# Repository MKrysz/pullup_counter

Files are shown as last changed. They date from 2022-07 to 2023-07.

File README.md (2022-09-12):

# Pullup Counter

## About

The main purpose of the project was to automatically count and save the amount of pullups I do to evaluate them later using python script. For this purpose I developed a small device mounted onto the bar. Other features include display for showing how many pullups were already done that day and USB serial port for easy to use interface with the device.

## Hardware

### PCB

Schematic

Schematic and PCB was made in KiCad.

For the power supply I decided that 2 AAA batteries would be the best choice, as they're easily available and have good volumetric energy density. Embedding the Li-Po battery was out of the table, because the project is stationary and charging wouldn't be possible.

As the brain of the device I went with STM32L0 series microcontroller because of following reasons:

- low power consumption and low operating voltage, which is mandatory in battery operated systems like this
- my familiarity with developing both harware and software development with this series
- affordable price.

I chose a STM32L051C8 as I had few of them lying around.

The MCU has a backup battery used for maintaining operation of RTC clock while main batteries are discharged or being replaced. The amount of pullups are displayed on 7 segment display as it's cheap, small and easy to drive. It's also perfect for displaying numbers which is all It's used here for. For a memory in which I would store my database i used a 512kB SPI Flash - P25Q40H. Communication with the device is done with USB serial port, so I included an USB port and USB-UART converter. I also included a capacitive touch pad and little sensor IC as a way to wake the device up. For detecting pullups I used proximity sesor consisting of IR Led diode and photodiode.

PCBs were manufactured by JLCPCB, and are shown below:
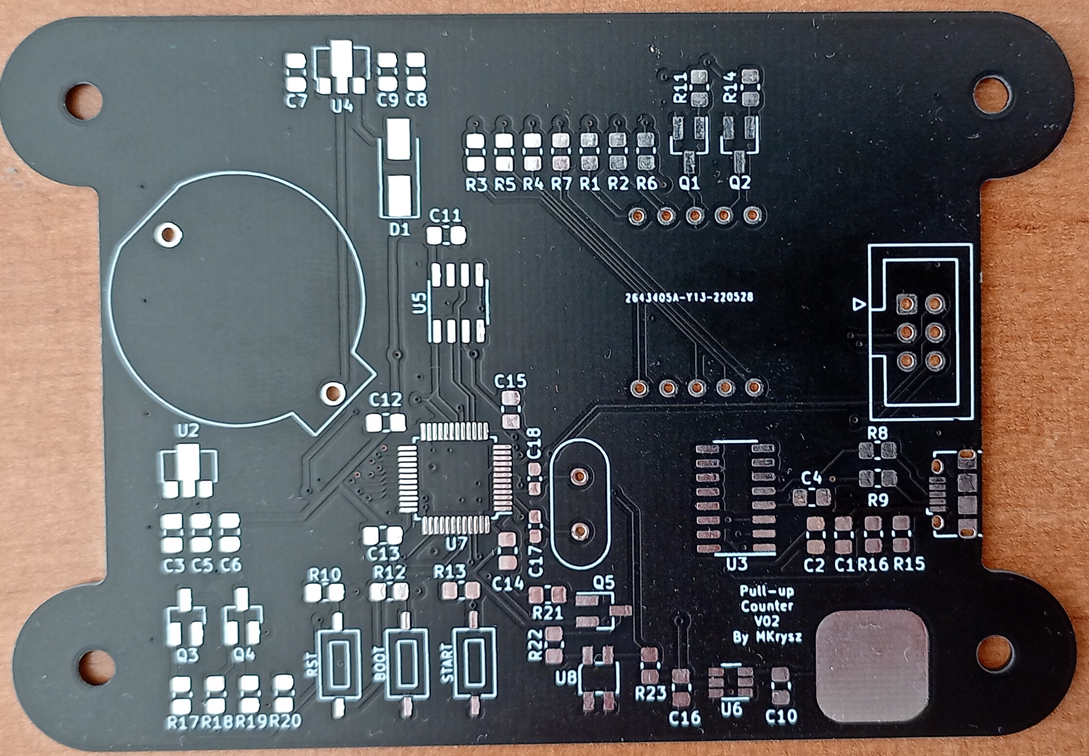
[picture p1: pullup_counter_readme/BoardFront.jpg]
Front

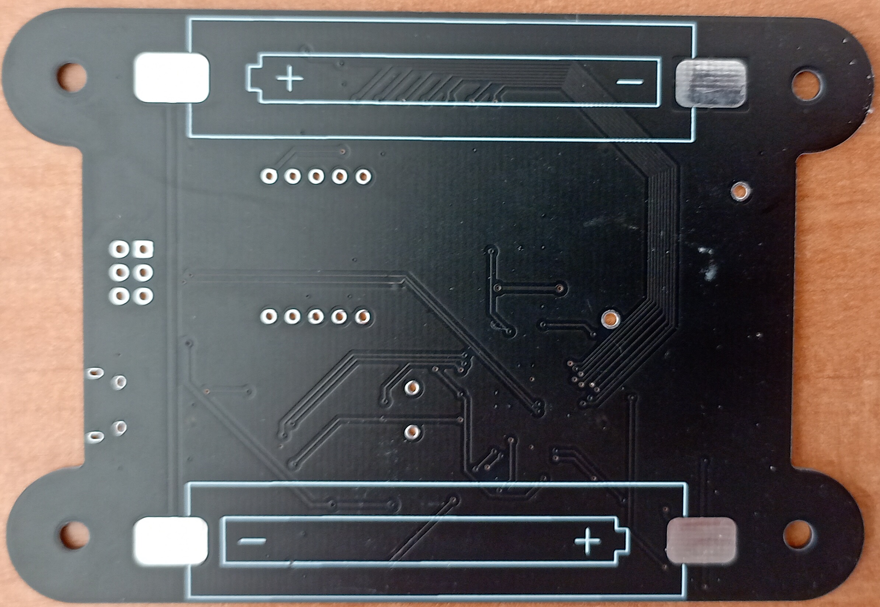
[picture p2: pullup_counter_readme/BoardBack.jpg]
Back


During soldering I found out that I'm out of SMD proximity sensors so I glued a THT one instead. Also, by accident, I soldered PNP transistors instead of NPN. After replacing the transistors I had to connect them to different pins of the MCU as the original ones were blown up.

After assembling and mounting it on the pullup bar:

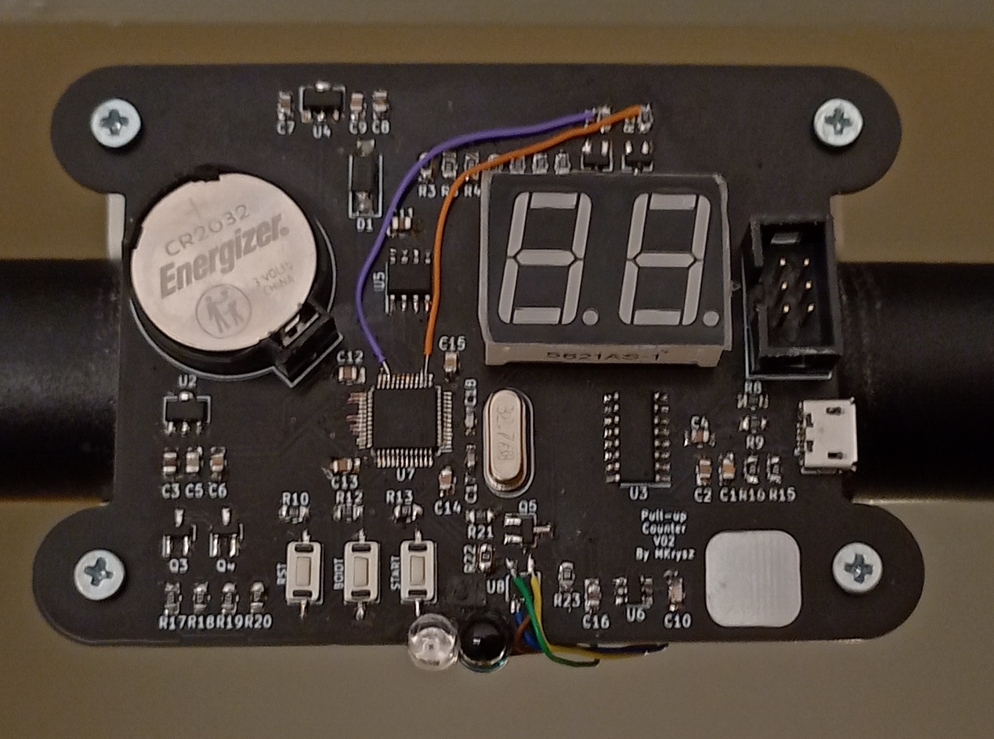
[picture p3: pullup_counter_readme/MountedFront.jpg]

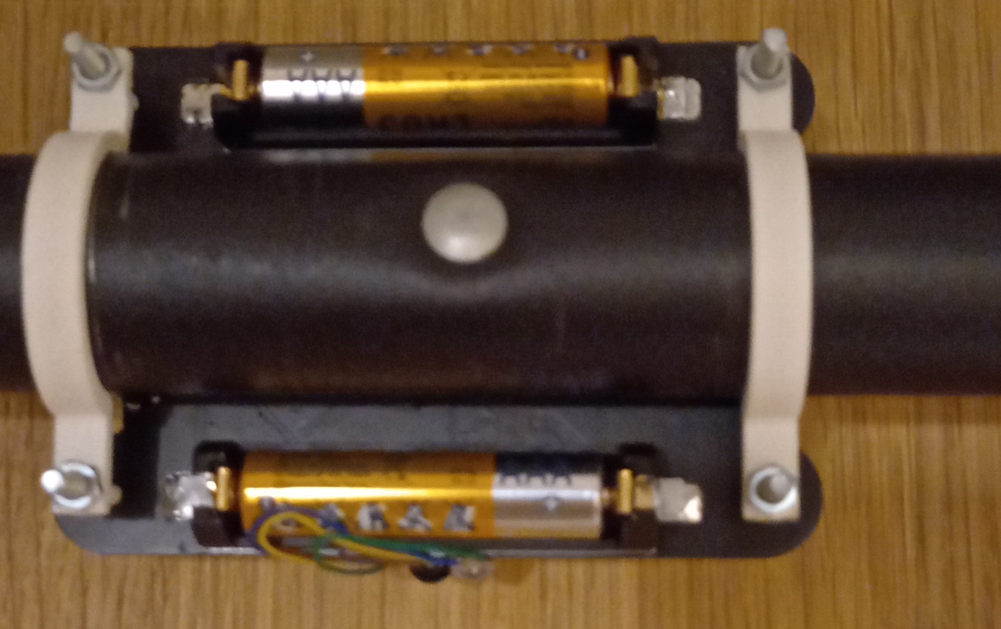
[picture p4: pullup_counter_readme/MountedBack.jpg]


### Mounting

Mounting is done using 3D-printed mounting system and four pairs of M3 bolts and nuts.

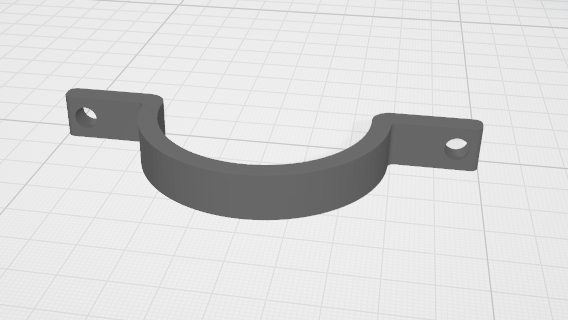
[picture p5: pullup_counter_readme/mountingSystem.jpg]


## Software

### Embedded

Project was made in VSCode using [stm32-for-vscode](https://github.com/bmd-studio/stm32-for-vscode) extension. For this project I used [stm32CubeMX](https://www.st.com/en/development-tools/stm32cubemx.html) for generating initialization code. I've also used nimaltd's [drivers for SPI flash memory](https://github.com/nimaltd/w25qxx).

The device must be woken up before every training session, which can be done either by physical button or capacitive touch pad. After that if device haven't detected a pullup within specified time, it goes back to sleep to prolong battery life.

Every pullup series is represented with following struct

```C

typedef struct _entry_struct
{
    uint32_t id; // unique id
    unsigned int count:6; // amount of pullups done in the series

    // timestamp
    unsigned int minute:6;
    unsigned int hour:5;
    unsigned int day:5;
    unsigned int month:4;
    unsigned int year:6;
}entry_t;

```

Because each entry's size is 8 bytes and my flash memory is 512kB the maximum amount of pullups that can be saved within the device is over 65 thousand

### USB User Interface

User interface allows the user for easy change of important parameters, debugging and downloading and  clearing data from device's flash memory. To put device in interface mode, plug it in your computer and restart it. The welcome message should appear. After that you can type 'help' for a list of available commands with short description.

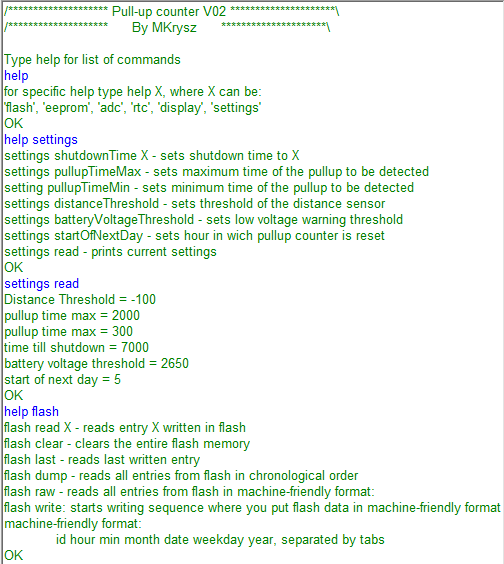
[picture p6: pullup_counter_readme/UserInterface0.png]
User Interface


### Data analysis

Python script that reads and interprets data acquired from the device.

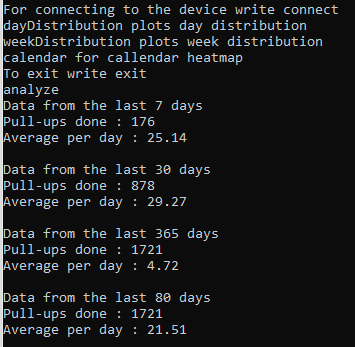
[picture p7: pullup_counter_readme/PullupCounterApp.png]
PullupCounterApp


Below are shown examples of generated plots:
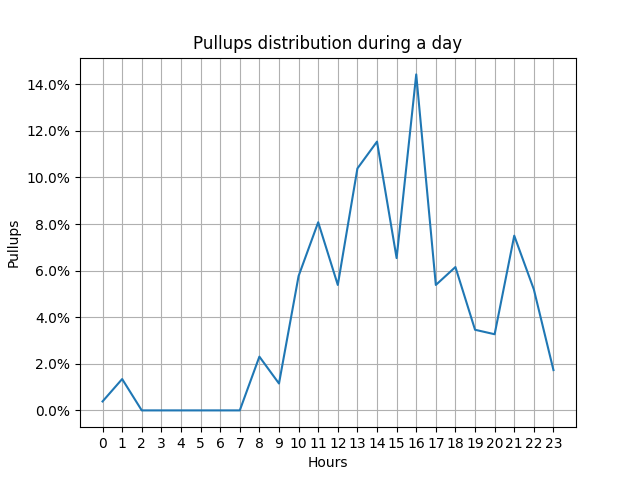
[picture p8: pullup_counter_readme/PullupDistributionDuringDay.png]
DayPlot

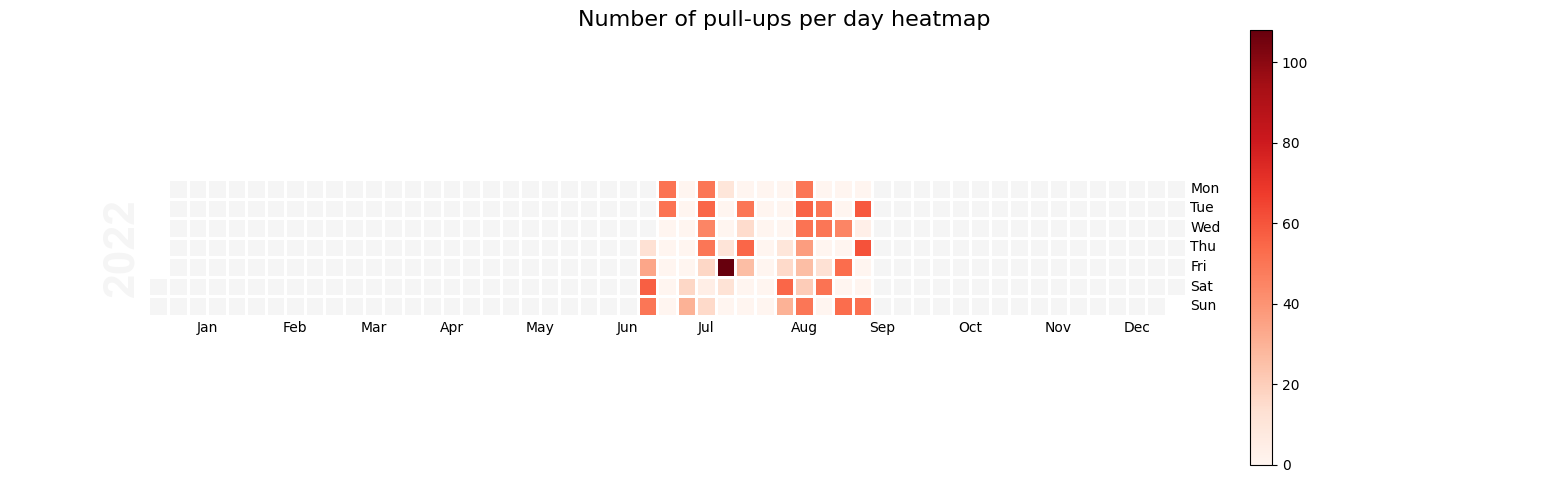
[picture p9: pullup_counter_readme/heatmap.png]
Heatmap


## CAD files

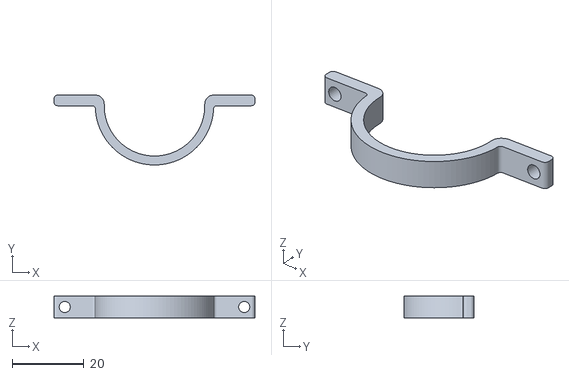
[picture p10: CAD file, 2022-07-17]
pullup_counter_models/mountingSystem.stl
56.0 x 19.5 x 6.00

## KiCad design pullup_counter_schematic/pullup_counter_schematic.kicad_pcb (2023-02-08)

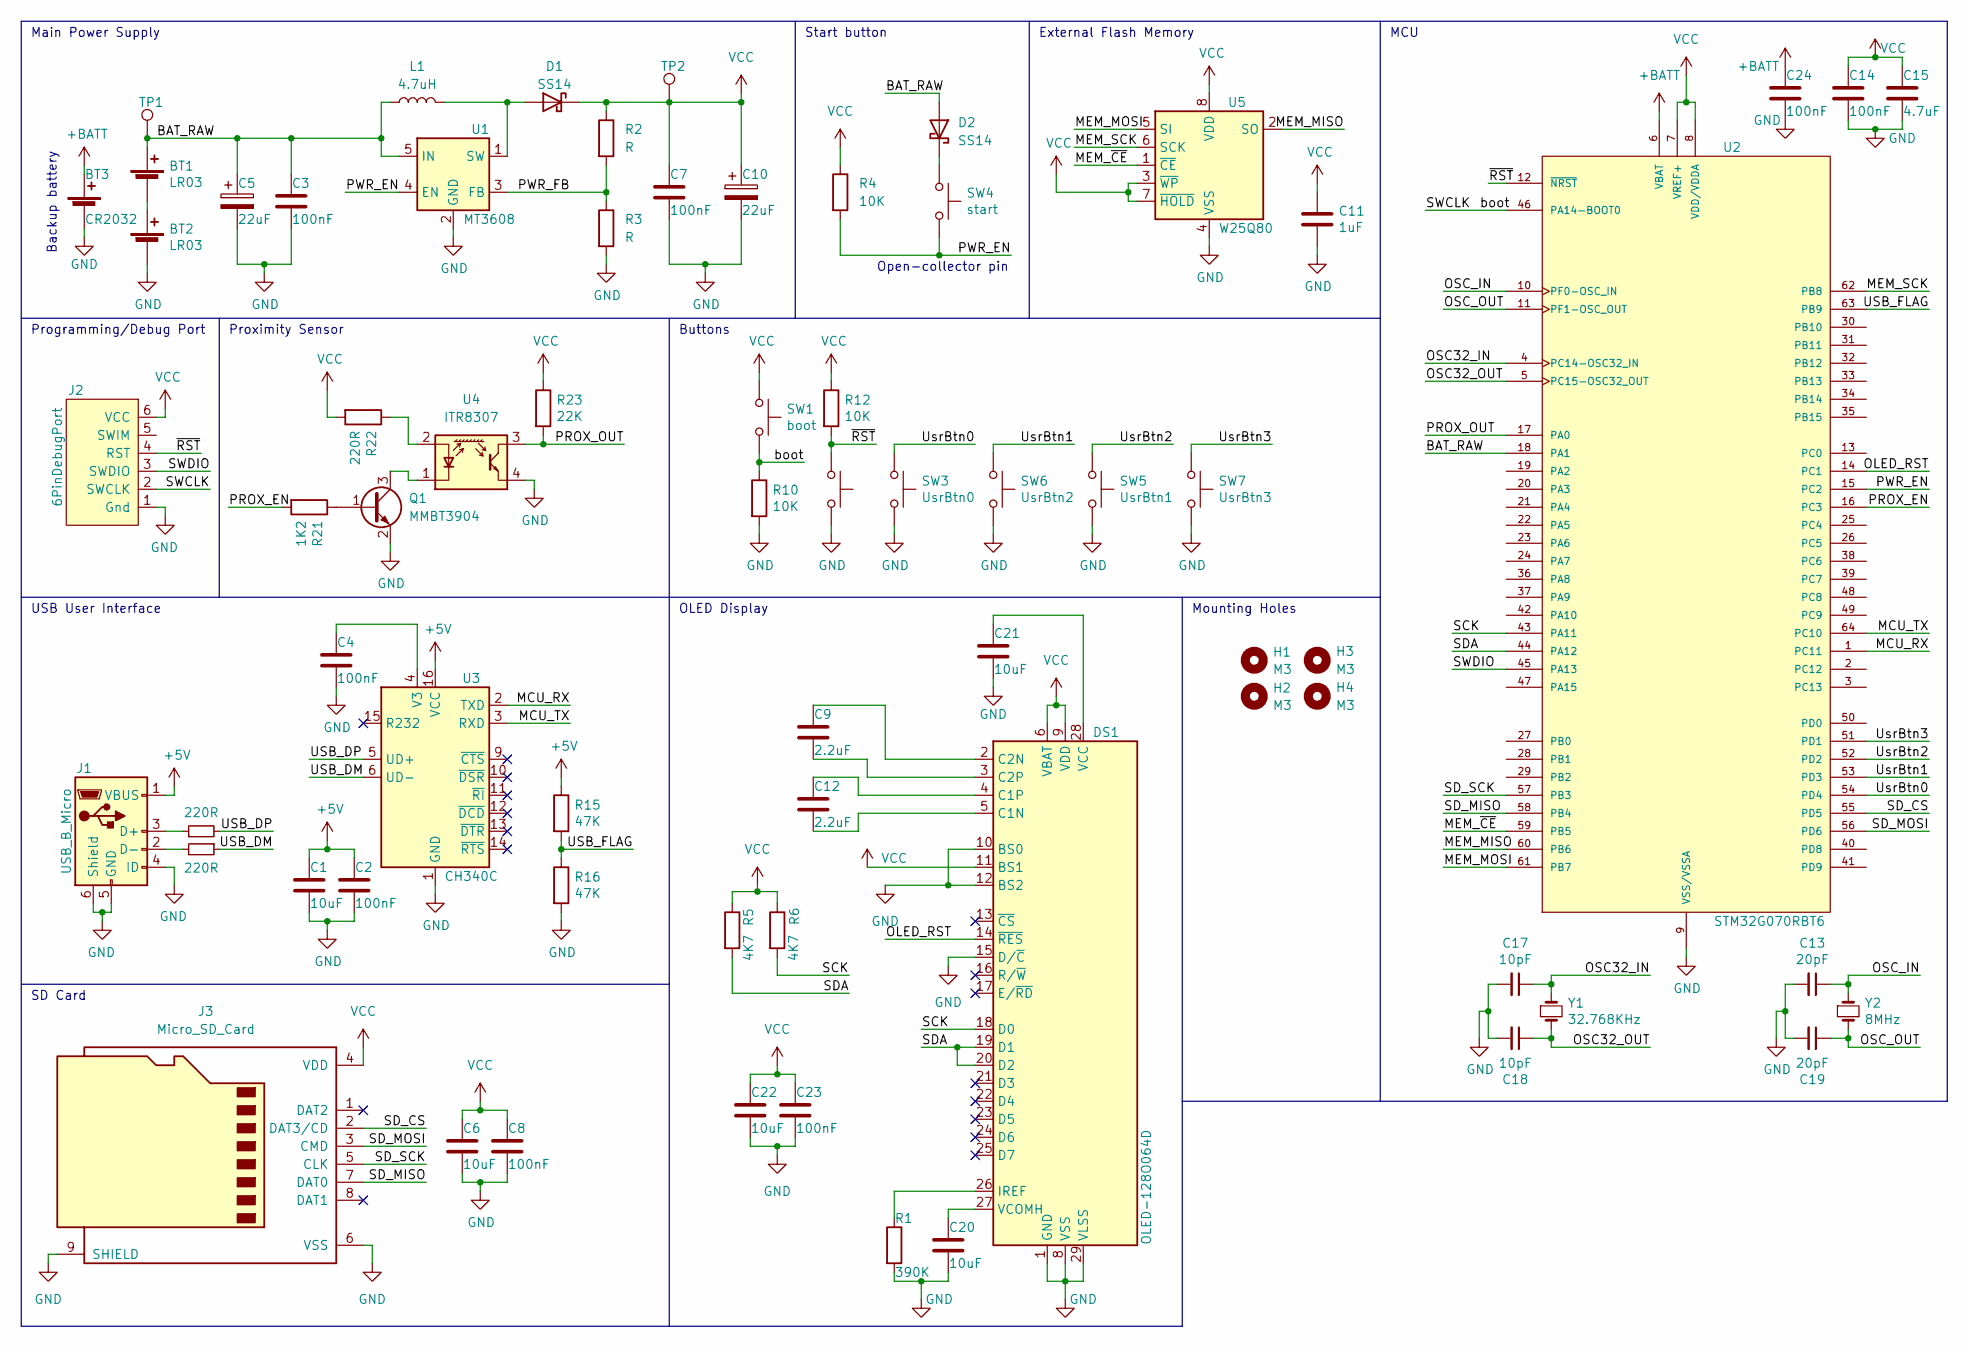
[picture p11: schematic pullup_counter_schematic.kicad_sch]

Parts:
BT1, BT2: LR03; SMD_SMT_AAA_LR03
BT3: CR2032; CR2032_CR2025_Battery_Holder
C1, C6, C20, C21, C22: 10uF; C_0805_2012Metric_Pad1.18x1.45mm_HandSolder
C2, C3, C4, C7, C8, C14, C23, C24: 100nF; C_0805_2012Metric_Pad1.18x1.45mm_HandSolder
C5, C10: 22uF; CP_Elec_5x4.5
C9, C12: 2.2uF; C_0805_2012Metric_Pad1.18x1.45mm_HandSolder
C11: 1uF; C_0805_2012Metric_Pad1.18x1.45mm_HandSolder
C13, C19: 20pF; C_0603_1608Metric_Pad1.08x0.95mm_HandSolder
C15: 4.7uF; C_0805_2012Metric_Pad1.18x1.45mm_HandSolder
C17, C18: 10pF; C_0603_1608Metric_Pad1.08x0.95mm_HandSolder
D1, D2: SS14; D_SMA
DS1: OLED-128O064D
H1, H2, H3, H4: M3; MountingHole_3.2mm_M3
J1: USB_B_Micro; USB_Micro-B_Amphenol_10118194_Horizontal
J2: 6PinDebugPort; IDC-Header_2x03_P2.54mm_Vertical
J3: Micro_SD_Card; uSD_socket
L1: 4.7uH; L_Ferrocore_DLG-0403
Q1: MMBT3904; SOT-23
R1: 390K; R_0805_2012Metric_Pad1.20x1.40mm_HandSolder
R2, R3: R; R_0805_2012Metric_Pad1.20x1.40mm_HandSolder
R4, R10, R12: 10K; R_0805_2012Metric_Pad1.20x1.40mm_HandSolder
R5, R6: 4K7; R_0805_2012Metric_Pad1.20x1.40mm_HandSolder
R8, R9, R22: 220R; R_0805_2012Metric_Pad1.20x1.40mm_HandSolder
R15, R16: 47K; R_0805_2012Metric_Pad1.20x1.40mm_HandSolder
R21: 1K2; R_0805_2012Metric_Pad1.20x1.40mm_HandSolder
R23: 22K; R_0805_2012Metric_Pad1.20x1.40mm_HandSolder
SW1: boot; TSB008
SW2: rst; TSB008
SW3: UsrBtn0; TSB008
SW4: start; sw_push_12_x_12_mm
SW5: UsrBtn1; TSB008
SW6: UsrBtn2; TSB008
SW7: UsrBtn3; TSB008
TP1, TP2: PinSocket_1x01_P2.54mm_Vertical
U1: MT3608; SOT-23-6
U2: STM32G070RBT6; LQFP-64_10x10mm_P0.5mm; PARTREV 1
U3: CH340C; SOIC-16_3.9x9.9mm_P1.27mm
U4: ITR8307; Everlight_ITR8307
U5: W25Q80; SOIC-8_5.275x5.275mm_P1.27mm
Y1: 32.768KHz; Crystal_HC49-4H_Vertical
Y2: 8MHz; Crystal_HC49-4H_Vertical

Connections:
+5V: C1.1, C2.1, J1.1 (VBUS), R15.1, U3.16 (VCC)
+BATT: BT3.1 (+), C24.1, U2.6 (VBAT)
/BAT_RAW: BT1.1 (+), C3.1, C5.1, D2.2 (A), L1.1, TP1.1, U1.5 (IN), U2.18 (PA1)
/MCU_RX: U2.1 (PC11), U3.2 (TXD)
/MCU_TX: U2.64 (PC10), U3.3 (RXD)
/MEM_MISO: U2.60 (PB6), U5.2 (SO)
/MEM_MOSI: U2.61 (PB7), U5.5 (SI)
/MEM_SCK: U2.62 (PB8), U5.6 (SCK)
/MEM_~CE: U2.59 (PB5), U5.1 (~CE)
/OLED_RST: DS1.14 (~RES), U2.14 (PC1)
/OSC32_IN: C17.1, U2.4 (PC14-OSC32_IN), Y1.1
/OSC32_OUT: C18.1, U2.5 (PC15-OSC32_OUT), Y1.2
/OSC_IN: C13.1, U2.10 (PF0-OSC_IN), Y2.1
/OSC_OUT: C19.1, U2.11 (PF1-OSC_OUT), Y2.2
/PROX_EN: R21.2, U2.16 (PC3)
/PROX_OUT: R23.2, U2.17 (PA0), U4.3 (C)
/PWR_EN: R4.2, SW4.2, U1.4 (EN), U2.15 (PC2)
/PWR_FB: R2.2, R3.1, U1.3 (FB)
/SCK: DS1.18 (D0), R6.2, U2.43 (PA11)
/SDA: DS1.19 (D1), DS1.20 (D2), R5.2, U2.44 (PA12)
/SD_CS: J3.2 (DAT3/CD), U2.55 (PD5)
/SD_MISO: J3.7 (DAT0), U2.58 (PB4)
/SD_MOSI: J3.3 (CMD), U2.56 (PD6)
/SD_SCK: J3.5 (CLK), U2.57 (PB3)
/SWCLK: J2.2 (SWCLK), R10.1, SW1.2, U2.46 (PA14-BOOT0)
/SWDIO: J2.3 (SWDIO), U2.45 (PA13)
/USB_DM: R9.1, U3.6 (UD-)
/USB_DP: R8.2, U3.5 (UD+)
/USB_FLAG: R15.2, R16.1, U2.63 (PB9)
/UsrBtn0: SW3.1, U2.54 (PD4)
/UsrBtn1: SW6.1, U2.53 (PD3)
/UsrBtn2: SW5.1, U2.52 (PD2)
/UsrBtn3: SW7.1, U2.51 (PD1)
/~RST: J2.4 (RST), R12.2, SW2.1, U2.12 (~NRST)
GND: BT2.2 (-), BT3.2 (-), C1.2, C2.2, C3.2, C4.2, C5.2, C6.2, C7.2, C8.2, C10.2, C11.2, C13.2, C14.2, C15.2, C17.2, C18.2, C19.2, C20.2, C21.2, C22.2, C23.2, C24.2, DS1.1 (GND), DS1.8 (VSS), DS1.10 (BS0), DS1.12 (BS2), DS1.15 (D/~C), DS1.29 (VLSS), DS1.30 (GND), J1.4 (ID), J1.5 (GND), J1.6 (Shield), J2.1 (Gnd), J3.6 (VSS), J3.9 (SHIELD), Q1.2 (E), R1.2, R3.2, R10.2, R16.2, SW2.2, SW3.2, SW5.2, SW6.2, SW7.2, U1.2 (GND), U2.9 (VSS/VSSA), U3.1 (GND), U4.4 (E), U5.4 (VSS)
unnamed: BT1.2 (-), BT2.1 (+)
unnamed: C4.1, U3.4 (V3)
unnamed: C9.1, DS1.2 (C2N)
unnamed: C9.2, DS1.3 (C2P)
unnamed: C12.1, DS1.4 (C1P)
unnamed: C12.2, DS1.5 (C1N)
unnamed: C20.1, DS1.27 (VCOMH)
unnamed: D1.2 (A), L1.2, U1.1 (SW)
unnamed: D2.1 (K), SW4.1
unnamed: DS1.26 (IREF), R1.1
unnamed: C21.1, DS1.28 (VCC)
unnamed: J1.2 (D-), R9.2
unnamed: J1.3 (D+), R8.1
unnamed: Q1.1 (B), R21.1
unnamed: Q1.3 (C), U4.1 (K)
unnamed: R22.1, U4.2 (A)
VCC: C6.1, C7.1, C8.1, C10.1, C11.1, C14.1, C15.1, C22.1, C23.1, D1.1 (K), DS1.6 (VBAT), DS1.9 (VDD), DS1.11 (BS1), J2.6 (VCC), J3.4 (VDD), R2.1, R4.1, R5.1, R6.1, R12.1, R22.2, R23.1, SW1.1, TP2.1, U2.7 (VREF+), U2.8 (VDD/VDDA), U5.3 (~WP), U5.7 (~HOLD), U5.8 (VDD)

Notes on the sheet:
OLED Display
USB User Interface
Main Power Supply
Programming/Debug Port
Open-collector pin
Backup battery
External Flash Memory
MCU
Start button
Proximity Sensor
Mounting Holes
SD Card
Buttons

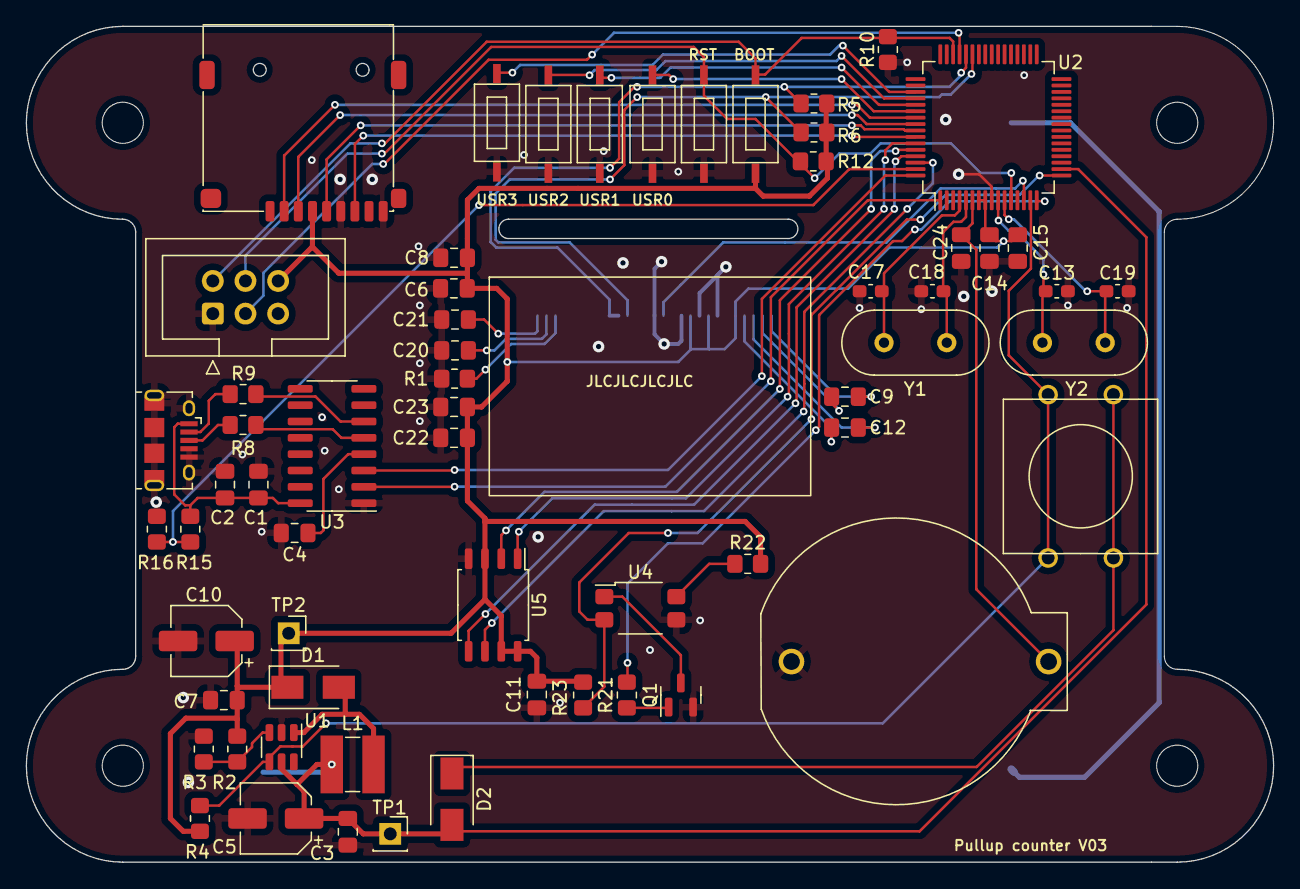
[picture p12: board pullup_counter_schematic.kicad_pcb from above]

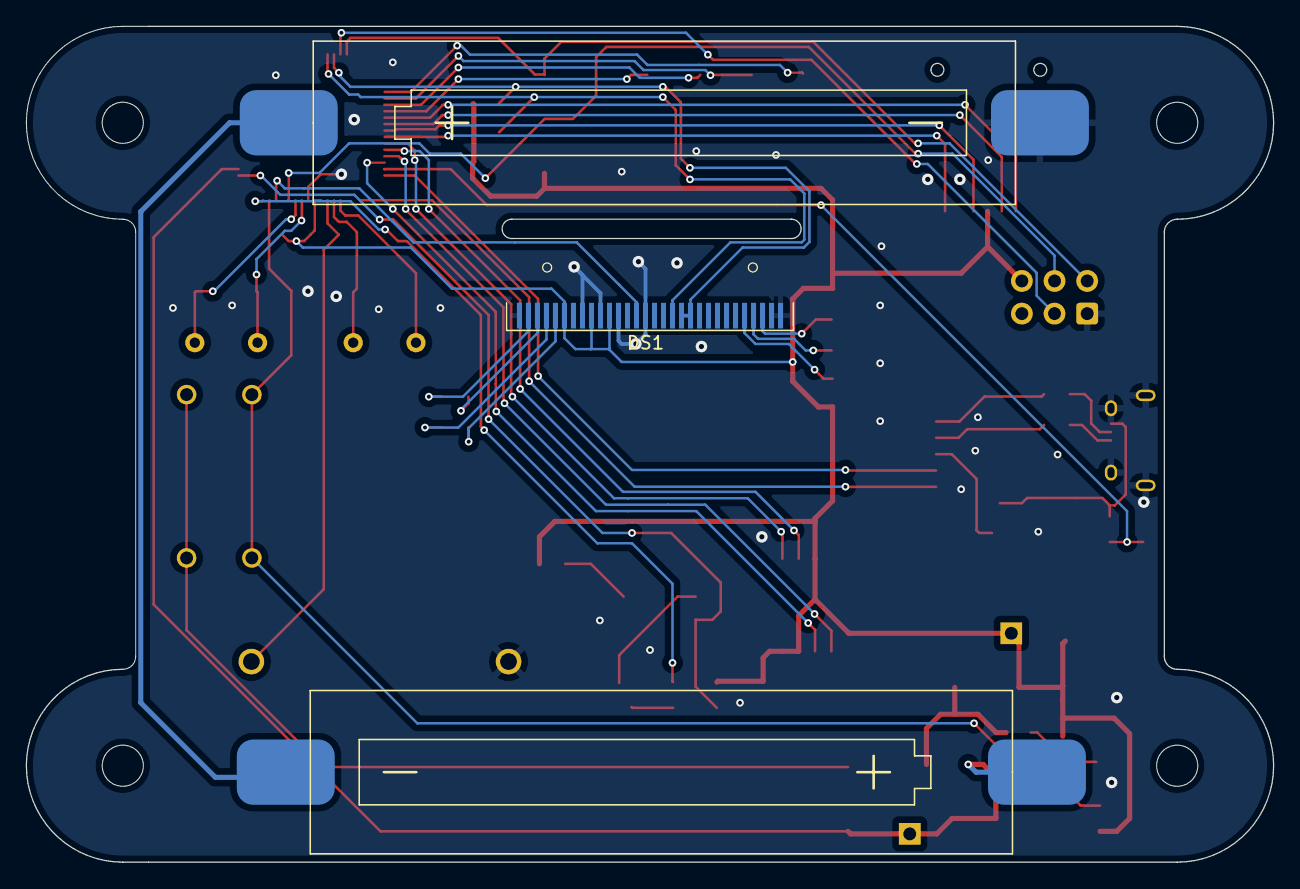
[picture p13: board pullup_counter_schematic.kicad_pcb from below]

Board: 2 copper layers, 97.0 x 65.0 mm, 69 parts (2 on the bottom side), 52 nets.

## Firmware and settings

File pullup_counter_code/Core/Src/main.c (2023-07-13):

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
/* Includes ------------------------------------------------------------------*/
#include "main.h"
#include "adc.h"
#include "dma.h"
#include "app_fatfs.h"
#include "i2c.h"
#include "rtc.h"
#include "spi.h"
#include "tim.h"
#include "usart.h"
#include "gpio.h"

/* USER CODE BEGIN Includes */
#include <string.h>
#include <stdbool.h>
#include <stdio.h>

#include "display.h"
#include "cli.h"
#include "entry.h"
#include "settings.h"
#include "config.h"
#include "flash.h"
#include "w25qxx.h"
#include "ssd1306.h"
/* USER CODE END Includes */


void SystemClock_Config(void);
/* USER CODE BEGIN PFP */
void programmingRoutine();
uint32_t measurePullupTime();
void SD_Update();
/* USER CODE END PFP */

/**
  * @brief  The application entry point.
  * @retval int
  */
int main(void)
{
  /* MCU Configuration--------------------------------------------------------*/

  /* Reset of all peripherals, Initializes the Flash interface and the Systick. */
  HAL_Init();

  /* Configure the system clock */
  SystemClock_Config();

  /* Initialize all configured peripherals */
  MX_GPIO_Init();
  MX_DMA_Init();
  MX_ADC1_Init();
  MX_I2C2_Init();
  MX_RTC_Init();
  MX_SPI1_Init();
  MX_SPI2_Init();
  MX_USART3_UART_Init();
  if (MX_FATFS_Init() != APP_OK) {
    Error_Handler();
  }
  MX_TIM6_Init();
  /* USER CODE BEGIN 2 */
  printf("Board Init\n\r");
  uint32_t timStart;

  timStart = HAL_GetTick();
  ADC_Init();
  printf("ADC_Init - %lums\n\r", HAL_GetTick()-timStart);


  timStart = HAL_GetTick();
  FLASH_Init();
  printf("Flash_init - %lums\n\r", HAL_GetTick()-timStart);

  timStart = HAL_GetTick();
  DISPLAY_Init();
  printf("Display_init - %lums\n\r", HAL_GetTick()-timStart);

  
  timStart = HAL_GetTick();
  FLASH_SettingsRead(&settings);
  FLASH_VarsRead(&eepromVars);
  printf("eeprom read - %lums\n\r", HAL_GetTick()-timStart);
  
  #ifdef PROGRAM_ROUTINE
  programmingRoutine();
  #endif

  // check battery voltage and warn of low voltage
  if(ADC_MeasureBattery() < settings.batteryVoltageThreshold){
    Display_SetMode(DispLowVoltage);
    // HAL_Delay(3000);
  }

  HAL_Delay(20);
  ADC_DistanceCalibrate();
  printf("Booting time = %lums\n\r", HAL_GetTick());
  
  ADC_PROX_ON();
  printf("Proximity sensor on\n");
  while(1){
    printf("%li\n", ADC_MeasureDistance());
    HAL_Delay(100);
  }
  /* USER CODE END 2 */

  /* Infinite loop */
  /* USER CODE BEGIN WHILE */


  uint8_t currentCount = 0;
  RTC_ReadTime();
  entry_t lastEntry;
  FLASH_EntryRead(&lastEntry, eepromVars.lastDdr);
  if(lastEntry.day != sDate.Date || lastEntry.month != sDate.Month || lastEntry.year != sDate.Year){
      eepromVars.pullup_counter = 0;
  }
  Display_SetMode(DispCounting);
  // count pull-ups loop
  uint32_t lastDetectedPullup = HAL_GetTick(); 
  // while(HAL_GetTick()-lastDetectedPullup < settings.timeTillShutdown){
  while(1) {
    if(flags.SD_Update)
      break;
    uint32_t timeDelta = measurePullupTime(); 
    if(settings.pullupTimeMin < timeDelta && timeDelta < settings.pullupTimeMax){
      lastDetectedPullup = HAL_GetTick();
      currentCount++;
      eepromVars.pullup_counter++;
    }
    if(task != task_normalOperation){
      break;
    }
  }
  ADC_PROX_OFF();
  
  if(currentCount != 0){

    uint32_t id = eepromVars.lastDdr;
    entry_t entry;
    entry.id = id;
    entry.count = currentCount;

    entry.year = sDate.Year;
    entry.month = sDate.Month;
    entry.day = sDate.Date;
    
    entry.hour = sTime.Hours;
    entry.minute = sTime.Minutes;
    eepromVars.lastDdr++;

    FLASH_EntryWrite(&entry, eepromVars.lastDdr);
    entry_t entryRead;
    FLASH_EntryRead(&entryRead, eepromVars.lastDdr);
    if(!ENTRY_IsEqual(&entry, &entryRead)){
      Display_SetMode(DispError);
    }
  }
  
  FLASH_VarsWrite(&eepromVars);
  FLASH_SettingsWrite(&settings);

  if(task == task_SD_Update){
    Display_SetMode(DispSD);
    SD_Update();
  }
  if(task == task_USB_handler){
    Display_SetMode(DispUSB);
    CLI_StartUserInterface();
  }

  #ifdef SLEEP_ENABLE
  HAL_SuspendTick();
  HAL_PWR_EnterSTOPMode(PWR_LOWPOWERREGULATOR_ON, PWR_STOPENTRY_WFI);
  #endif

  #ifdef SHUTDOWN_ENABLE
  HAL_GPIO_WritePin(PWR_EN_GPIO_Port, PWR_EN_Pin, 0);
  #endif

  while (1)
  {
    /* USER CODE END WHILE */

    /* USER CODE BEGIN 3 */
  }
  /* USER CODE END 3 */
}

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
/* USER CODE BEGIN 4 */

void programmingRoutine()
{
  #ifdef SET_RTC
    RTC_SetCurrentTime();
  #endif

  #ifdef ERASE_FLASH
    W25qxx_EraseChip();
  #endif

  #ifdef RESET_SETTINGS
    settings.distanceThreshold = -250;
    settings.pullupTimeMax = 2000;
    settings.pullupTimeMin = 300;
    settings.timeTillShutdown = 7000;
    settings.batteryVoltageThreshold = 2650;
  #endif

  #ifdef RESET_EEPROM
    eepromVars.lastDdr = 0;
    eepromVars.pullup_counter = 0;
  #endif

}

uint32_t measurePullupTime()
{
  uint32_t pullupStart = HAL_GetTick();
  while(ADC_MeasureDistance() < settings.distanceThreshold);
  uint32_t pullupEnd = HAL_GetTick();
  uint32_t timeDelta = pullupEnd - pullupStart;
  return timeDelta;
}

void SD_Update()
{
  FATFS FatFs;  //Fatfs handle
  FIL fil;  //File handle
  FRESULT fres; //Result after operations  
  uint32_t startingID; // starting id
  const char fileName[] = "pullup_data.csv";
  char buffer[128];
  unsigned int br; // number of bytes actualy read from f_read()
  entry_t entry;

  fres = f_mount(&FatFs, "", 1); //1=mount now

  fres = f_open(&fil, fileName, FA_READ|FA_OPEN_EXISTING);
  switch (fres)
  {
  case FR_OK:
    while(1){ //seek last entry
      f_gets(buffer, 128, &fil);
      if(f_eof(&fil)){
        break;
      }
    }
    ENTRY_CreateFromString(&entry, buffer);
    startingID = entry.id;
    f_close(&fil);
    fres = f_open(&fil, fileName, FA_WRITE|FA_OPEN_APPEND);
    break;

  case FR_NO_FILE:
    startingID = 0;
    f_close(&fil);
    fres = f_open(&fil, fileName, FA_WRITE|FA_CREATE_NEW);
    f_puts(ENTRY_RawFormat, &fil);
    f_putc('\n', &fil);
    break;

  default:
    break;
  }

  uint32_t curID = startingID;
  while(curID < eepromVars.lastDdr){
    FLASH_EntryRead(&entry, curID);
    ENTRY_ToStrings(&entry, buffer);
    f_puts(buffer, &fil);
    f_putc('\n', &fil);
    SD_Done = (curID - startingID)*100/(eepromVars.lastDdr-startingID);
    curID++;
  }

  f_close(&fil);
}

/* USER CODE END 4 */
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


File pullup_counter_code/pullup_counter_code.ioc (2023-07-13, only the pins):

Mcu.UserName=STM32G070RBTx
PA0.GPIO_Label=PROX_OUT
PA0.Signal=ADC1_IN0
PA1.GPIO_Label=BAT_RAW
PA1.Signal=ADC1_IN1
PA13.Signal=SYS_SWDIO
PA14-BOOT0.Signal=SYS_SWCLK
PB3.Signal=SPI1_SCK
PB4.Signal=SPI1_MISO
PB5.GPIO_Label=FLASH_CS
PB5.Signal=GPIO_Output
PB6.Signal=SPI2_MISO
PB7.Signal=SPI2_MOSI
PB8.Signal=SPI2_SCK
PB9.GPIO_Label=USB_FLAG
PB9.Signal=GPXTI9
PC1.GPIO_Label=OLED_RST
PC1.Signal=GPIO_Output
PC10.Signal=USART3_TX
PC11.Signal=USART3_RX
PC2.GPIO_Label=PWR_EN
PC2.Signal=GPIO_Output
PC3.GPIO_Label=PROX_EN
PC3.Signal=GPIO_Output
PD1.GPIO_Label=UsrBtn3
PD1.Signal=GPXTI1
PD2.GPIO_Label=UsrBtn2
PD2.Signal=GPXTI2
PD3.GPIO_Label=UsrBtn1
PD3.Signal=GPXTI3
PD4.GPIO_Label=UsrBtn0
PD4.Signal=GPXTI4
PD5.GPIO_Label=SD_CS
PD5.Signal=GPIO_Output
PD6.Signal=SPI1_MOSI

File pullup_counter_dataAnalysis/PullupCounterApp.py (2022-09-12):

from time import time
from pullupSerial import PullupSerial
from datetime import datetime, timedelta
import matplotlib.pyplot as plt
import matplotlib.ticker as mtick
import pandas as pd
import numpy as np
from copy import deepcopy
import calmap


welcomeMsg = \
    "For connecting to the device write connect\n"\
    "dayDistribution plots day distribution\n"\
    "weekDistribution plots week distribution\n"\
    "calendar for callendar heatmap\n"\
    "To exit write exit\n"

def ConnectAndUpdate():
    pullupCounter = PullupSerial(debug=True)
    pullupCounter.PortList()
    portNr = int(input("Choose port (just number):\n"))
    pullupCounter.PortConnect(portNr)
    pullupCounter.RTC_Update()
    pullupCounter.DataBackupUpdate()
    pullupCounter.PortDisconnect()
    return 0

def plotDayDistribution(data):
    data = pd.read_table('data.txt', delimiter = ' ')
    temp = data.groupby(["Hour"]).count()["Id"]
    N = len(data)

    plotData = []
    hourCounter = 0
    for hour, val in temp.iteritems():
        while(hourCounter < hour):
            plotData.append(0)
            hourCounter+=1
        plotData.append(val/N)
        hourCounter+=1

    plt.plot([i+0.5 for i in range(24)], plotData)
    plt.xlabel("Hours")
    plt.ylabel("Pullups")
    plt.title("Pullups distribution during a day")
    plt.grid('on')
    plt.xticks([i for i in range(24)])
    plt.gca().yaxis.set_major_formatter(mtick.PercentFormatter(xmax=1.0))
    plt.show()


def plotCalendarHeatmap(data):
    data = deepcopy(data)
    data = pd.Series(data.Count.values, data['datetime'])
    fig, ax = calmap.calendarplot(data)                                                                                                                          
    fig.colorbar(ax[0].get_children()[1], ax=ax.ravel().tolist())  
    fig.suptitle('Number of pull-ups per day heatmap', fontsize=16)
    plt.show()

def plotWeekDistribution(data):
    data = pd.read_table('data.txt', delimiter = ' ')
    temp = data.groupby(["Weekday"]).count()["Id"]
    N = len(data)

    plotData = []
    weekdayCounter = 0
    for weekday, val in temp.iteritems():
        weekday -= 1
        while(weekdayCounter < weekday):
            plotData.append(0)
            weekdayCounter+=1
        plotData.append(val/N)
        weekdayCounter+=1

    text_values = ["Mon", "Tue", "Wed", "Thu", "Fri", "Sat", "Sun"]
    plt.bar([i for i in range(7)], plotData, align='center')
    plt.xlabel("Weekday")
    plt.ylabel("Pullups")
    plt.xticks([i for i in range(7)], text_values)
    plt.gca().yaxis.set_major_formatter(mtick.PercentFormatter(xmax=1.0))
    plt.title("Pullups distribution during a week")
    plt.grid('on')
    plt.show()

def readData():
    data = pd.read_table('data.txt', delimiter = ' ')
    data.set_index('Id', inplace = True)
    data['Year'] = data['Year'] + 2000
    data['datetime'] = pd.to_datetime(data[["Year", "Month", "Day", "Hour", "Minute"]])
    data = data.drop(['Year', 'Month', 'Day', 'Hour', 'Minute'], axis=1)
    return data


def generalDataAnalysis(data, nrOfDays):
    # startDate = datetime.now() - timedelta(days=nrOfDays)
    # data = data.drop(data[(data.datetime < startDate)].index)
    SumOfPullups = data.Count.sum()
    print('Data from the last', nrOfDays, 'days')
    print('Pull-ups done :', SumOfPullups)
    print('Average per day : {:.2f}'.format(SumOfPullups/nrOfDays))
    print()

def analyze():
    data = readData()
    yesterday = datetime.now() - timedelta(days=1)
    DateWeek = yesterday - timedelta(days=7)
    DateMonth = yesterday - timedelta(days=30)
    DateYear = yesterday - timedelta(days=365)

    temp = data[(DateWeek < data.datetime)]
    temp = temp[temp.datetime < yesterday]
    generalDataAnalysis(temp, 7)
    temp = data[(DateMonth < data.datetime)]
    temp = temp[temp.datetime < yesterday]
    generalDataAnalysis(temp, 30)
    temp = data[(DateYear < data.datetime)]
    temp = temp[temp.datetime < yesterday]
    generalDataAnalysis(temp, 365)
    
    startDate = data['datetime'][0]
    generalDataAnalysis(data, (datetime.now() - startDate).days)

    plotDayDistribution(data)
    plotCalendarHeatmap(data)

def interface():
    while(1):
        cmd = input(welcomeMsg)
        if (cmd in ("exit", "x")):
            break
        elif(cmd in ("connect", 'con')):
            ConnectAndUpdate()
        elif(cmd in ("dayDistribution", 'day')):
            plotDayDistribution(0)
        elif(cmd in ("weekDistribution", 'week')):
            plotWeekDistribution(0)
        elif(cmd in ("calendar", 'cal')):
            plotCalendarHeatmap(0)
        elif(cmd in ('analyze', 'a')):
            analyze()
        else:
            print("Unknown command")
    return 0

def test():
    analyze()
    return 0

def main():
    interface()
    # test()

if __name__ == '__main__':
    main()

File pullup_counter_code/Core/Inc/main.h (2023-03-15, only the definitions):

#define OLED_RST_Pin GPIO_PIN_1
#define OLED_RST_GPIO_Port GPIOC
#define PWR_EN_Pin GPIO_PIN_2
#define PWR_EN_GPIO_Port GPIOC
#define PROX_EN_Pin GPIO_PIN_3
#define PROX_EN_GPIO_Port GPIOC
#define PROX_OUT_Pin GPIO_PIN_0
#define PROX_OUT_GPIO_Port GPIOA
#define BAT_RAW_Pin GPIO_PIN_1
#define BAT_RAW_GPIO_Port GPIOA
#define UsrBtn3_Pin GPIO_PIN_1
#define UsrBtn3_GPIO_Port GPIOD
#define UsrBtn3_EXTI_IRQn EXTI0_1_IRQn
#define UsrBtn2_Pin GPIO_PIN_2
#define UsrBtn2_GPIO_Port GPIOD
#define UsrBtn2_EXTI_IRQn EXTI2_3_IRQn
#define UsrBtn1_Pin GPIO_PIN_3
#define UsrBtn1_GPIO_Port GPIOD
#define UsrBtn1_EXTI_IRQn EXTI2_3_IRQn
#define UsrBtn0_Pin GPIO_PIN_4
#define UsrBtn0_GPIO_Port GPIOD
#define UsrBtn0_EXTI_IRQn EXTI4_15_IRQn
#define SD_CS_Pin GPIO_PIN_5
#define SD_CS_GPIO_Port GPIOD
#define FLASH_CS_Pin GPIO_PIN_5
#define FLASH_CS_GPIO_Port GPIOB
#define USB_FLAG_Pin GPIO_PIN_9
#define USB_FLAG_GPIO_Port GPIOB
#define USB_FLAG_EXTI_IRQn EXTI4_15_IRQn

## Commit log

2022-05-13 Upload Version 01
    [pullup_counter_schematic-B_Cu.gbl, pullup_counter_schematic-B_Mask.gbs, pullup_counter_schematic-B_Paste.gbp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]
2022-05-13 Uploaded offline work
    [pullup_counter_schematic.sch]
2022-05-16 Created STM32L051 project
2022-05-16 Created PCB
    [pullup_counter_schematic.kicad_pcb, pullup_counter_schematic.sch]
2022-05-18 Runned DRC and fixed some problems
    [pullup_counter_schematic.kicad_pcb]
2022-05-18 Added models
    [obejma2.0001.ipt, obejma2.ipt, obejma2.stl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]
2022-05-27 Generated PCB's Gerbers
    [pullup_counter_schematic-B_Cu.gbl, pullup_counter_schematic-B_Mask.gbs, pullup_counter_schematic-B_Paste.gbp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]
2022-06-02 CubeMX is now compatible with schematic
2022-06-02 CubeMX compatible with schematic
2022-06-05 Changed mcu to STM32L051
2022-06-10 Calculated value of remaining components
    [pullup_counter_schematic.sch]
2022-06-12 Display works; UART properly receives data
2022-06-14 CLI improvements; EEPROM fixed;
    [adc.c, cli.c, display.c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]
2022-06-14 External Interrupts now work properly
2022-06-22 Upload of STL model of the clamp
    [Clamp.stl]
2022-07-17 Started writing readme
    [pullup_counter_schematic.sch]
2022-07-17 Schematic image now shows up
2022-07-17 Added correct model
    [Clamp.stl, mountingSystem.stl, obejma2.0001.ipt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]
2022-07-26 Python interface for the device created
2022-07-26 WeekDistribution plot addded and added placeholder for calendar heatmap
2022-07-29 Heatmap calendar works
2022-08-13 Fixed bug causing the second pullup zeroing display and added config.h
    [main.c]
2022-09-12 RTC clock corrected, changed the order of initialization
    [main.c, pullup_counter_code.ioc, rtc.c]
2022-09-12 Excluded current day from general analysis and cleared the workspace
2023-02-06 Added step-up, SD-Card, OLED display and changed MCU
    [pullup_counter_schematic.kicad_pcb, pullup_counter_schematic.kicad_sch]
2023-02-06 Changed proximity sens to SMD, added more USR btns
    [pullup_counter_schematic.kicad_pcb, pullup_counter_schematic.kicad_sch]
2023-02-07 Minor fixes
    [pullup_counter_schematic.kicad_pcb, pullup_counter_schematic.kicad_sch]
2023-02-08 Generated gerbers for hardware V03
    [pullup_counter_schematic-B_Cu.gbl, pullup_counter_schematic-B_Mask.gbs, pullup_counter_schematic-B_Paste.gbp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]
2023-02-08 Added printf
2023-03-07 Deleted unnecessary files in schematic
    [pullup_counter_schematic-B_Cu.gbl, pullup_counter_schematic-B_Mask.gbs, pullup_counter_schematic-B_Paste.gbp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]
2023-03-25 Trying to fix display
    [adc.c, main.c, pullup_counter_code.ioc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]
2023-03-29 Fixed SPI Flash; Started work on proximity sensor
    [pullup_counter_schematic.kicad_sch, sheet.ods]
2023-07-13 some debugging/schematic fixing
    [pullup_counter_schematic.kicad_sch]
2023-07-14 cleared up kicads libs and footprints
    [pullup_counter_schematic.kicad_sch]

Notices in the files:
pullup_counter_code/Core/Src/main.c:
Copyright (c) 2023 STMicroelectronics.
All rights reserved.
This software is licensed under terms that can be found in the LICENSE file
